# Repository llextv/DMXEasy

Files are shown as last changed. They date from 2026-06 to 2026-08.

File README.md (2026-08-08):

**DMX EASY**
DIY DMX lighting controller based on ESP32, featuring 6 faders, 53 buttons and a custom 3D-printed enclosure.
I made this project because I need an DMX Table but its so expensive

## Overview
Features:
- 6 channel faders
- 53 programmable buttons
- DMX512 output
- Dual ESP32 architecture
- 3D printable enclosure
- Low-cost and easily reproducible design

## Hardware
See the BOM in [bom.csv](BOM.csv) or at the end of file

## Recap:
**Case:**
face1
face2
face3
face4

**Assembly**
assemblingAll
assemblingAll2

**Scheme:**
scheme
scheme
scheme
scheme
scheme
scheme
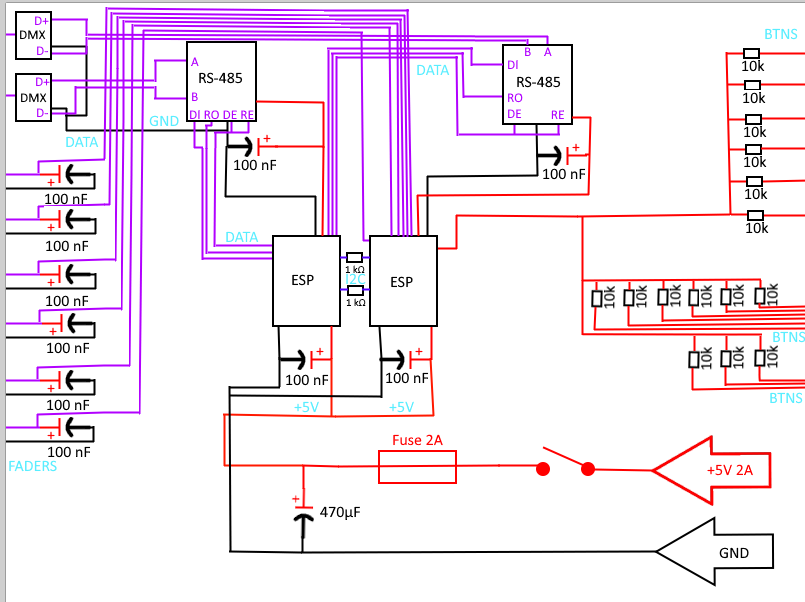
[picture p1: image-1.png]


**Script**
[Here script files](dev/ESP/ESP_DMX/DMX_Controller/DMX_Controller.ino)

**Files**
[Case](assets\DMXEasy.step)
[Case Bottom](assets\BottomDMXEasy.step)
[Assembly](assets\AssemblageDMXEasy.step)
[Scheme](assets\scheme.pdn)

## BOM
| Catégorie  | Article | Quantité | Prix unitaire (€) | Prix total (€) | Notes | URL |
| --- | --- | ---: | ---: | ---: | --- | --- |
| Controls | Fader | 6 | 1.50 | 9.00 | | [https://fr.aliexpress.com/item/1005006152089336.html](https://fr.aliexpress.com/item/1005006152089336.html) |
| Controls | Button | 1 | 14.79 | 14.79 | Lot de 53 boutons | [https://fr.aliexpress.com/item/1005003911184656.html](https://fr.aliexpress.com/item/1005003911184656.html) |
| Controls | ESP-WROOM-32 | 2 | 5.00 | 10.00 | 1 pour logique/DMX, 1 pour gestion des entrées | [https://fr.aliexpress.com/item/1005005655238798.html](https://fr.aliexpress.com/item/1005005655238798.html) |
| Controls | MAX485 Module RS-485 | 1 | 2.44 | 2.44 | Lot de 2 modules | [https://fr.aliexpress.com/item/1005005737922222.html](https://fr.aliexpress.com/item/1005005737922222.html) |
| Power | Alimentation 5V 4A | 1 | 9.59 | 9.59 | | [https://fr.aliexpress.com/item/1005008468643815.html](https://fr.aliexpress.com/item/1005008468643815.html) |
| Power | Condensateur électrolytique 470uF 16V | 1 | 3.99 | 3.99 | | [https://fr.aliexpress.com/item/1005009417460390.html](https://fr.aliexpress.com/item/1005009417460390.html) |
| Power | Condensateurs céramiques 100nF 50V (20 pcs) | 1 | 6.09 | 6.09 | | [https://fr.aliexpress.com/item/1005012122696428.html](https://fr.aliexpress.com/item/1005012122696428.html) |
| Power | Interrupteur ON/OFF | 1 | 1.13 | 1.13 | | [https://fr.aliexpress.com/item/1005010015277754.html](https://fr.aliexpress.com/item/1005010015277754.html) |
| Power | Résistance 1kΩ | 1 | 4.39 | 4.39 | | [https://fr.aliexpress.com/item/1005011813359681.html](https://fr.aliexpress.com/item/1005011813359681.html) |
| Power | Résistance 10kΩ | 1 | 5.19 | 5.19 | | [https://fr.aliexpress.com/item/1005011813359681.html](https://fr.aliexpress.com/item/1005011813359681.html) |
| Power | Résistance 120Ω | 1 | 5.19 | 5.19 | | [https://fr.aliexpress.com/item/1005011813359681.html](https://fr.aliexpress.com/item/1005011813359681.html) |
| Power | Diodes (100 pcs) | 1 | 0.94 | 0.94 | | [https://fr.aliexpress.com/item/1005002339916163.html](https://fr.aliexpress.com/item/1005002339916163.html) |
| Power | Connecteurs XLR 3 broches | 1 | 4.19 | 4.19 | Lot de 4 connecteurs | |
| Power | Jack alimentation DC | 1 | 1.23 | 1.23 | | [https://fr.aliexpress.com/item/1005011863804603.html](https://fr.aliexpress.com/item/1005011863804603.html) |
| Power | Porte-fusible panneau | 1 | 1.79 | 1.79 | Lot de 10 | |
| Power | Fusible verre 250V 2A | 1 | 1.96 | 1.96 | | |
| Prototype  | Plaque de prototypage PCB | 1 | 3.19 | 3.19 | | |
| Prototype  | Fil électrique | 1 | 2.79 | 2.79 | | [https://fr.aliexpress.com/item/1005006996255957.html](https://fr.aliexpress.com/item/1005006996255957.html) |
| Prototype  | Étain de soudure | 1 | 4.59 | 4.59 | | [https://fr.aliexpress.com/item/1005009973086759.html](https://fr.aliexpress.com/item/1005009973086759.html) |
| Prototype  | Gaine thermorétractable | 1 | 2.19 | 2.19 | Kit 164 pcs | |
| Impression | PLA 1 kg | 1 | 15.99 | 15.99 | | [https://fr.aliexpress.com/item/1005007175412873.html](https://fr.aliexpress.com/item/1005007175412873.html) |
| **TOTAL**  | | | | **115.94** | | |

## How it's works ?
DMXEasy is a low-cost DIY DMX controller based on two ESP32 microcontrollers.
The user interacts with the controller using the 53 buttons and 6 faders. The buttons are arranged in a matrix to reduce the number of GPIO pins required. The faders provide analog values that can be read by the ESP32.
One ESP32 is dedicated to handling the physical inputs, while the second ESP32 handles the controller logic and generates the DMX512 data.
The general data flow is:
Buttons / Faders
       ↓
Input ESP32
       ↓
Control data
       ↓
Main ESP32
       ↓
DMX512 data
       ↓
MAX485
       ↓
XLR DMX output
       ↓
DMX lighting fixtures

When a button is pressed or a fader is moved, the input ESP32 detects the change and sends the corresponding control information to the main ESP32. The main ESP32 processes this information and updates the DMX values.
The updated DMX data is then transmitted using the DMX512 protocol. Since DMX512 uses an RS-485 physical layer, a MAX485 module is used to convert the ESP32's serial signal into the differential signal required by DMX.
The final result is that changing a control on the physical console changes the corresponding DMX values sent to the lighting fixtures.
The project is designed so that the hardware remains relatively simple and inexpensive while providing a physical interface for controlling DMX equipment.

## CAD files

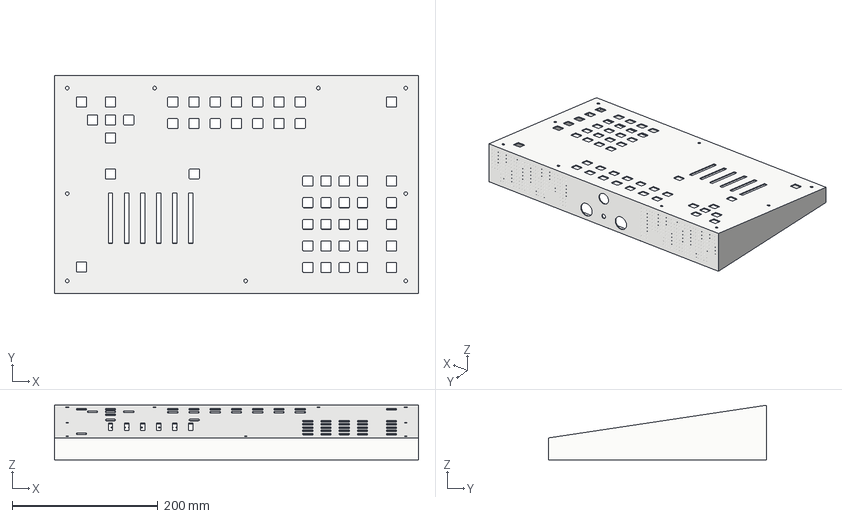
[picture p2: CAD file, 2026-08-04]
assets/DMXEasy.step
500.0 x 300.0 x 75.0 mm

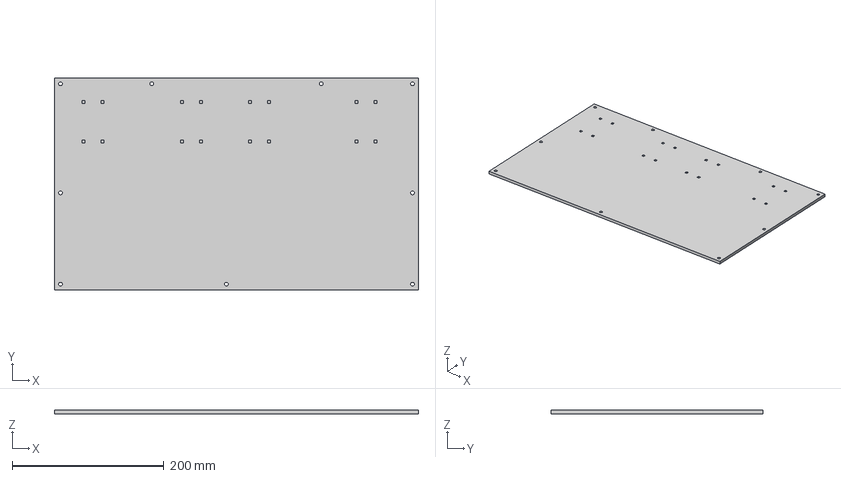
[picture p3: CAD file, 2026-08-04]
assets/BottomDMXEasy.step
480.0 x 280.0 x 5.00 mm

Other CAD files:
assets/AssemblageDMXEasy.step
assets/AssemblageDMXEasy.f3z

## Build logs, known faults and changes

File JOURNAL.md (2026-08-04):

---
title: "DMXEasy"
author: "llextv"
description: "A plate for manage all DMX easely and not expensive"
created_at: "2026-05-29"
---

# May 31: Reflection about product

My idea is to create a plate like Wolfmix ? for DMX Management without having to spend a fortune and easily reproducible.

My inspiration was this:
Inspi wolfmix
Inspi DMX Controler

And this is my idea on paper: 
Paper inspi

A app for tablet for dashboard controlled by this dmx table.

All flux generate from slider ... going to be outputed in 2 DMX universe & (1 Art/net ??)

BOM of components:

- 6 faders (https://fr.aliexpress.com/item/1005006152089336.html) = 6 * 1.5€
- 53 buttons (https://fr.aliexpress.com/item/1005003911184656.html) = 1 * 14,79€

For controll:
- 2x ESP-WROOM-32 (https://fr.aliexpress.com/item/1005005655238798.html) = 2*5€
  -> One for logic and generate DMX
  -> One for manage inputs
- 2x  MAX485 Module RS-485 (https://fr.aliexpress.com/item/1005005737922222.html) = 1*2.44€

For power:
- Power 5V 4A (https://fr.aliexpress.com/item/1005008468643815.html) = 1 * 9,59€
- Electrolytic Capacitor (470uF 16V) (https://fr.aliexpress.com/item/1005009417460390.html) = 1 * 3,99€
- 20Pcs Ceramic capacitor 50V (100nF 50V) (https://fr.aliexpress.com/item/1005012122696428.html) = 1 * 6,09€
- ON-Off Toggle Switch (https://fr.aliexpress.com/item/1005010015277754.html) = 1 * 1.13€
- 1k Ohm (https://fr.aliexpress.com/item/1005011813359681.html) = 1 * 4,39€
- 10k Ohm (https://fr.aliexpress.com/item/1005011813359681.html) = 1 * 5.19€
- 120 Ohm (https://fr.aliexpress.com/item/1005011813359681.html) = 1 * 5.19€
- 100 x Diode (https://fr.aliexpress.com/item/1005002339916163.html) = 1 * 0,94€
- XLR 3Pin Panel Mount Connectors (4PCS XLR 3Pin Panel Mount Connectors Male/Female Durable Metal Housing Silver Jack for Pro Audio Mic Speaker) = 1 * 4.19€
- DC Power Jack (https://fr.aliexpress.com/item/1005011863804603.html) = 1 * 1,23€
- Panel Mount Fuse (10pcs/lot Panel Mount PCB Fuse Holder Case with transparent Cover 5x20mm 250V) = 1 * 1.79€
- Glass Fuse 250V 2A = 1 * 1.96€

Proto:
- PCB Circuit Prototyping Board (PCB Circuit Prototyping Board Double Side Prototype Boards DIY Universal Printed Perfboard Electronic Kit) = 1 * 4.79€
- Wire (https://fr.aliexpress.com/item/1005003269498051.html) = 1 * 3.99€

For a total of 93,86 € (without PCB / 3D print (and fail ...)) = arround $109,45

**Total time spent: 4 hours**

# June 1: Electric design ...

This is total BOM:
2 × ESP32-WROOM-32
2 × MAX485
6 × faders 10k
53 × boutons
53 × 1N4148
8 × 10kΩ
2 × 1kΩ
2 × 120Ω
1 × 330Ω
10 × 100nF
2 × 470µF
1 × fusible 2A + support
1 × interrupteur
1 × jack DC 5.5×2.1
2 × XLR DMX
perfboard + câblage

This is tinkercad scheme:


For buttons matrices

For the moment it's this:


This is finished:


I spend lot of time on this scheme because I made multiple calques for allow me to separate differents components or electrical / data wire for example ...

**Total time spent: 3 hours**

# June 2: KiCad

Today I work on 3d print
For size of hole:
14 mm × 14 mm per switches
70 mm × 5 à 6 mm per fader

This is my design:



I have alrealy make swicthe hole so it's easy (more than fader because I never made this)

All of this go to be print in 3d for the moment I think (for debug i would like to print just the top of plate)

**Total time spent: 3 hours**

# June 3: Software

Today, I start to build software (it's very difficult for the moment to see where I go with my script lol):
Here is code with help of AI (not tested because I cannot), AI help me to make base without errors, my jobs is to connect all principally
This is code:
(Available in dev/ESP/ESP_DMX/DMX Controller)



My time are spend on understand code (I'm web dev, not arduino dev lol)
I also make reflection about documentation from JSON libs, esp_dmx and other librairies

**Total time spent: 2.5 hours**

# June 4: Update scheme
First, I clean my scheme and I made lot of calques in my scheme, it's allow me to disable part of circuit for precision/

scheme

I start a big part of scheme: adressing all wire (I spend lot of time in this because check of all documentation of all component of this circuit)
wireScheme

**Total time spent: 3.5 hours**

# June 5: Keycaps occupation
Today, my job is to find good keycaps or create one example
I have find this:
keycaps

[KeycapsLink](https://cults3d.com/fr/mod%C3%A8le-3d/divers/blank-keycap-bottom-row-1-25u)

Differents problem with this keycaps:
-> At the base it's for resine print
-> size of 1.25U but my switches is 1U ? I gonna try ...
All keycaps will be 3D printed

My work now is to estimate price of print
cura1
This config of print optimised for supports
cura2
cura3

One keycaps:
cura4

So beautiful: 
cura5

Finally it's this for 53 btns
cura6

Finally it's this:
cura7

arround 120g of plastic

**Total time spent: 2 hours**

# June 6: Constrain occupation
I start to make reflection arround constraint of our dmx table.

First constrain: Strenght
I need to add feet to my design to support the top; we'll have to see when that's printed.
fusion1

Second constrain: Heat
I need to think about adding ventilation: first option: add one or two fans to remove the heat.

Thirth constrain: size of print
I need to think of a way to join different 3D printed parts together.
First idea: heat them to melt whatever would bond them?
Second idea: hot glue (no, I'm kidding lol)

I now need to confirm my solutions:
for First constrain I will wait all component for see

Second constrain:
Make grid for stay air pass on the case
I think ventirad is overkill for my case ?
constrain2
(is back of my case)
I halso add a hole:
holeconstrain2
(for 2 universe and 1 power)
btnconstrain2
I also add a hole for ON/OFF btn

Thirth constrain:
I print little part for test heat it
Constrain3

**Total time spent: 4 hours**

# June 7: Safety Check & other info
Go make a safety check:
- Put a heat shrink tubing for each connexion (164PCS 2: 1 Cable Shrink Tube Kit Heat Assorted Pack Thermoretractile Insulation Sleeving Cable Wire Shrink Wrapping for DIY) = 1 * 2.19€

We need to do something to fix each component:
For ESP:
ESP

For MAX485:
MAX485

I have made an assembling with this:
assembling

What I need:
- Tin cable for welding (https://fr.aliexpress.com/item/1005009973086759.html) = 1 * 4,59€

**Total time spent: 3.5 hours**

# June 8: Recap all my docs for see where I go
All is in title !

**BOM:**
- 6 faders (https://fr.aliexpress.com/item/1005006152089336.html) = 6 * 1.5€ = 9€
- 53 buttons (https://fr.aliexpress.com/item/1005003911184656.html) = 1 * 14,79€

For controll:
- 2x ESP-WROOM-32 (https://fr.aliexpress.com/item/1005005655238798.html) = 2*5€ = 10€
  -> One for logic and generate DMX
  -> One for manage inputs
- 2x  MAX485 Module RS-485 (https://fr.aliexpress.com/item/1005005737922222.html) = 1*2.44€

For power:
- Power 5V 4A (https://fr.aliexpress.com/item/1005008468643815.html) = 1 * 9,59€
- Electrolytic Capacitor (470uF 16V) (https://fr.aliexpress.com/item/1005009417460390.html) = 1 * 3,99€
- 20Pcs Ceramic capacitor 50V (100nF 50V) (https://fr.aliexpress.com/item/1005012122696428.html) = 1 * 6,09€
- ON-Off Toggle Switch (https://fr.aliexpress.com/item/1005010015277754.html) = 1 * 1.13€
- 1k Ohm (https://fr.aliexpress.com/item/1005011813359681.html) = 1 * 4,39€
- 10k Ohm (https://fr.aliexpress.com/item/1005011813359681.html) = 1 * 5.19€
- 120 Ohm (https://fr.aliexpress.com/item/1005011813359681.html) = 1 * 5.19€
- 100 x Diode (https://fr.aliexpress.com/item/1005002339916163.html) = 1 * 0,94€
- XLR 3Pin Panel Mount Connectors (4PCS XLR 3Pin Panel Mount Connectors Male/Female Durable Metal Housing Silver Jack for Pro Audio Mic Speaker) = 1 * 4.19€
- DC Power Jack (https://fr.aliexpress.com/item/1005011863804603.html) = 1 * 1,23€
- Panel Mount Fuse (10pcs/lot Panel Mount PCB Fuse Holder Case with transparent Cover 5x20mm 250V) = 1 * 1.79€
- Glass Fuse 250V 2A = 1 * 1.96€

Proto:
- PCB Circuit Prototyping Board (PCB Circuit Prototyping Board Double Side Prototype Boards DIY Universal Printed Perfboard Electronic Kit) = 1 * 3,19€
- Wire (https://fr.aliexpress.com/item/1005006996255957.html) = 1 * 2,79€
- Tin cable for welding (https://fr.aliexpress.com/item/1005009973086759.html) = 1 * 4,59€
- Heat shrink tubing for each connexion (164PCS 2: 1 Cable Shrink Tube Kit Heat Assorted Pack Thermoretractile Insulation Sleeving Cable Wire Shrink Wrapping for DIY) = 1 * 2.19€

For print:
- 1 Kg PLA (https://fr.aliexpress.com/item/1005007175412873.html) = 1 * 15,99€

Total: 
115,94€ = $135,22

I made aliexpress shopping card:
aliexpress
so I remake all link of my BOM and all prices

**Case:**
face1
face2
face3
face4

**Scheme:**
scheme
scheme
scheme
scheme
scheme
scheme

**Script**
[Here script files](dev/ESP/ESP_DMX/DMX_Controller/DMX_Controller.ino)

**Files**
[Case](assets\DMXEasy.f3d)
[Scheme](assets\scheme.pdn)

I'm now ready for build it, I think

**Total time spent: 3 hours**

# June 16: After wait I have received response about my project

I have received this message from reviewer:
Hey! 
You will need an assembled model of the project with all the electronics components and case, also I am unable to understand your wiring diagram, please have a clean labelled diagram and dont forget to upload the step files for CAD :3

Whats I understand:
- I need to make a assembling file for case
- Scheme is actually difficult to read ?

First pb:
I decided: I hate Fusion 360, cannot import stl because of cloud space .... lot of bugs...
assemblingAll
assemblingAll2

See file in assets\AssemblageDMXEasy.f3z

Second pb:
newScheme
I added data on my scheme but I would like to know what's cannot be understand ?
Maybe the buttons part or faders part because it corresponds to the matrix diagram that was created on Tinkercad ? scheme

And the files are in assets file of repo for the scheme.pdn (paint.net) & Fusion 360 file
**Total time spent: 4 hours**

## July 16: After 1 month of wait I have response

"Heyaa, I see in your journal that you have made the changes requested in last review but you forgot to have those updated in the readme, also i really recommend adding labels in your wiring diagram which makes it easier for everyone to read and understand :3"

So for patching this I update my README.md with all informations
and I adding some labels on my diagrams


**Total time spent: 1 hours**

## Response and return
I have a response for my project:

"Hey, cool idea, but you need to fix the approach of mounting electronic components for stable design before final approval.

Specifically, I see you are trying to mount the component by adding pillar-like structure that will support four corners of your electronics. However, since it is not attached to the main case, it is highly unlikely it will stand still at fixed place. My recommendation would be adding floor (detachable) in the case, and making hole that aligns to position of holes on your electronics so you can use screws and nuts to tightly hold them together:)

Also, add .step file of final assembly on your github pls '3'"

"

So with this message I detect 4 problems:
-> Fixation of component
-> Support not fixed at main structure
-> Floor detecheable
-> .step file and assembly in github

So for each problem:
- fixation of component:
I made hole in my bottom structure for fix component fixture:
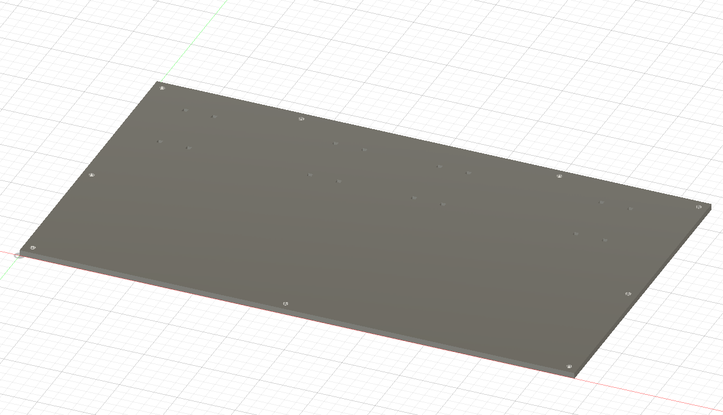
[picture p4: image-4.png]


- support for main structure:
I add hole for M5.5 between bottom and top
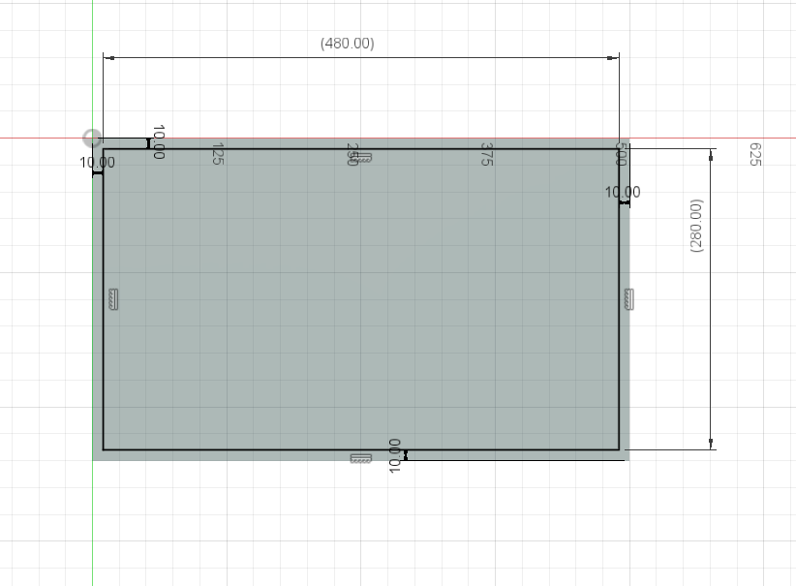
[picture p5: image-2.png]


- floor detecheable:
"I add hole for M5.5 between bottom and top
" --> same
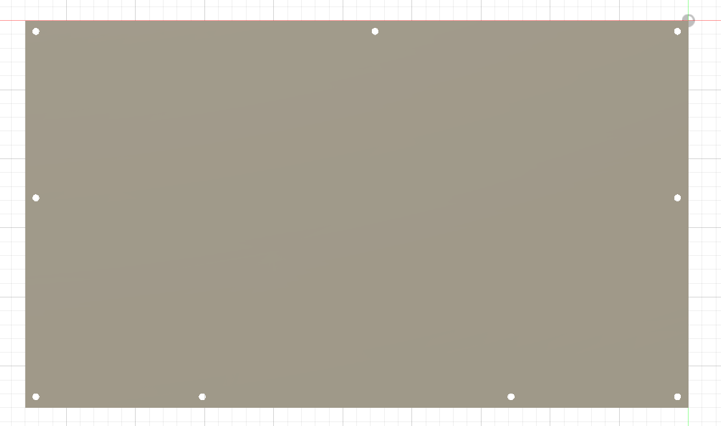
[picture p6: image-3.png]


- step file:
I remake a big assembly with all:
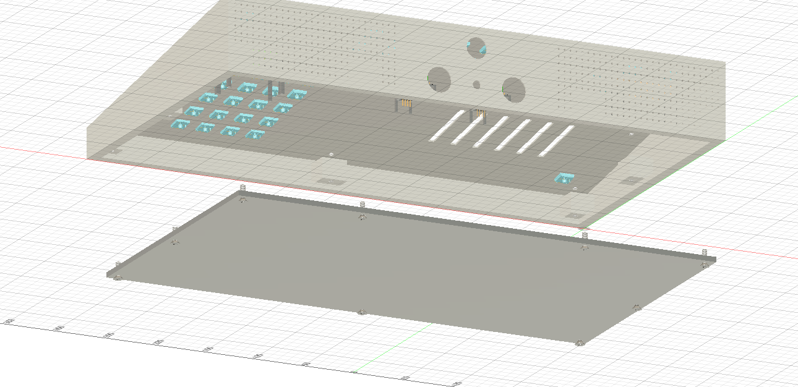
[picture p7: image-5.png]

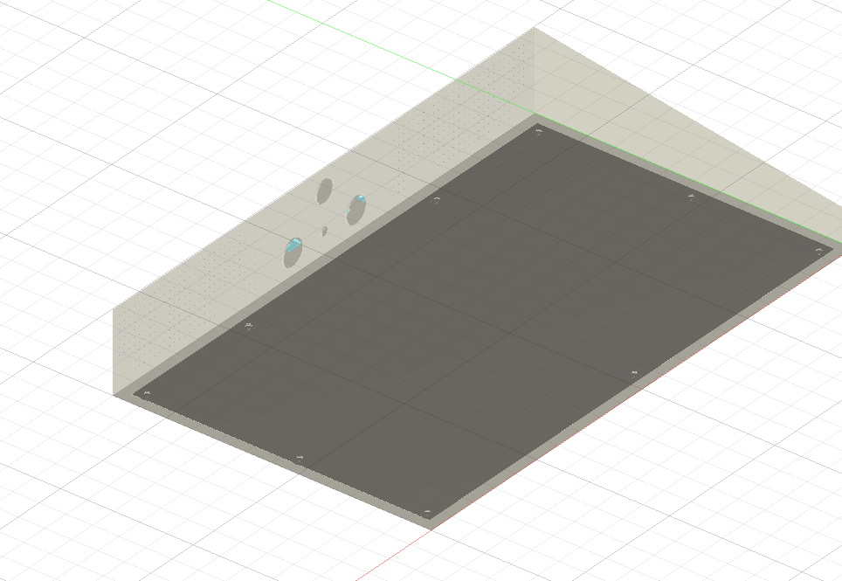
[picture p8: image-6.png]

AssemblageDMXEasy.step

This is the final idea but for arrived to this product I also try to make closing like battery (pile) juste to close with push but I check how to make but no find in fusion ?
So I made basically

**Total time spent: 3.5 hours**

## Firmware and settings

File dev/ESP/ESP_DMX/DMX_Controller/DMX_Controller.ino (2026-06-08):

#include "UARTReceiver.h"
#include "DMXEngine.h"
#include "DMXOutput.h"
#include "SceneEngine.h"

unsigned long lastDMX = 0;

void setup()
{
  Serial.begin(115200);
  uartReceiver.begin();
  sceneEngine.begin();
  dmx.begin();
  dmxOutput.begin();
}

void loop()
{
  uartReceiver.update();
  sceneEngine.update();
  dmx.update();
  if(millis() - lastDMX >= 25)
  {
    lastDMX = millis();
    dmxOutput.update();
  }
}

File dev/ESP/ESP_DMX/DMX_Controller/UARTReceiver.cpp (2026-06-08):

#include "UARTReceiver.h"
#include "StateManager.h"

UARTReceiver uartReceiver;

HardwareSerial InputSerial(2);

void UARTReceiver::begin()
{
  InputSerial.begin(
    115200,
    SERIAL_8N1,
    16,
    17
  );
}

void UARTReceiver::update()
{
  while(InputSerial.available())
  {
    char c = InputSerial.read();
    if(c == '\n')
    {
      parseLine(buffer);
      buffer = "";
    }
    else
    {
      buffer += c;
    }
  }
}

void UARTReceiver::parseLine(String line)
{
  line.trim();
  if(line.startsWith("BTN:"))
  {
    int first = line.indexOf(':');
    int second = line.indexOf(':', first + 1);
    int id = line.substring(first + 1, second).toInt();
    int value = line.substring(second + 1).toInt();
    if(id >= 0 && id < 64)
    {
      controller.buttons[id] = value;
    }
  }
  else if(line.startsWith("FADER:"))
  {
    int first = line.indexOf(':');
    int second = line.indexOf(':', first + 1);
    int id = line.substring(first + 1, second).toInt();
    int value = line.substring(second + 1).toInt();
    if(id >= 0 && id < 6)
    {
      controller.faders[id] = value;
    }
  }
}

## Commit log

2026-06-08 nine day
    [DMXEasy.f3d]
2026-06-08 push it
    [BOM.csv]
2026-06-16 ten day
    [AssemblageDMXEasy.f3z]
2026-08-04 change with new returned project
    [AssemblageDMXEasy.f3z, AssemblageDMXEasy.step, BottomDMXEasy.step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]
2026-11-08 Fix image links in Assembly section
    Updated image links for the assembly section in README.
2026-11-08 Correct image link for assemblingAll
    Fix image link formatting in README.md
2026-11-08 Fix image link for assemblingAll in README.md
2026-11-08 Fix formatting and enhance project documentation
    Updated journal entries to correct formatting and improve clarity. Revised README.md, BOM.csv, and added details to project documentation.
